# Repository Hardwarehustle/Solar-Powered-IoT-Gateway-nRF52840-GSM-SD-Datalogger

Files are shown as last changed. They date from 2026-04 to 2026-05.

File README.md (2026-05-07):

# Solar-Powered IoT Gateway — nRF52840 + GSM + SD Datalogger
---

## Project Overview

This is a **solar-powered, battery-backed IoT Gateway PCB** built around the **Nordic nRF52840** SoC (Bluetooth 5 + USB + 64 MHz Cortex-M4F). It integrates a complete off-grid power system with MPPT solar charging, 2× AA battery holders, GSM connectivity via SIM800L, timestamped microSD data logging via DS3231 RTC, EEPROM configuration storage, and a u.FL antenna connector — all on a compact square board with 4 mounting holes.

The board is designed for **remote outdoor IoT deployments** such as environmental monitoring, asset tracking, agricultural sensors, and smart metering — where grid power is unavailable and cellular connectivity is the only uplink.

**Key capabilities:**
-  **Solar MPPT charging** of LiPo/Li-ion battery via CN3791
-  **BLE 5.0 / NFC / USB** via nRF52840
-  **GSM 2G connectivity** via SIM800L (SMS, GPRS)
-  **MicroSD card** data logging (SPI, level-shifted via 74LVC125A)
-  **DS3231 RTC** with AT24C32 EEPROM for timestamped logging
-  **SWD JTAG** debug/programming header
-  **FACTORY + RESET** tactile buttons
-  **Power + Status LEDs**

---

##  Project Visuals

### Schematic
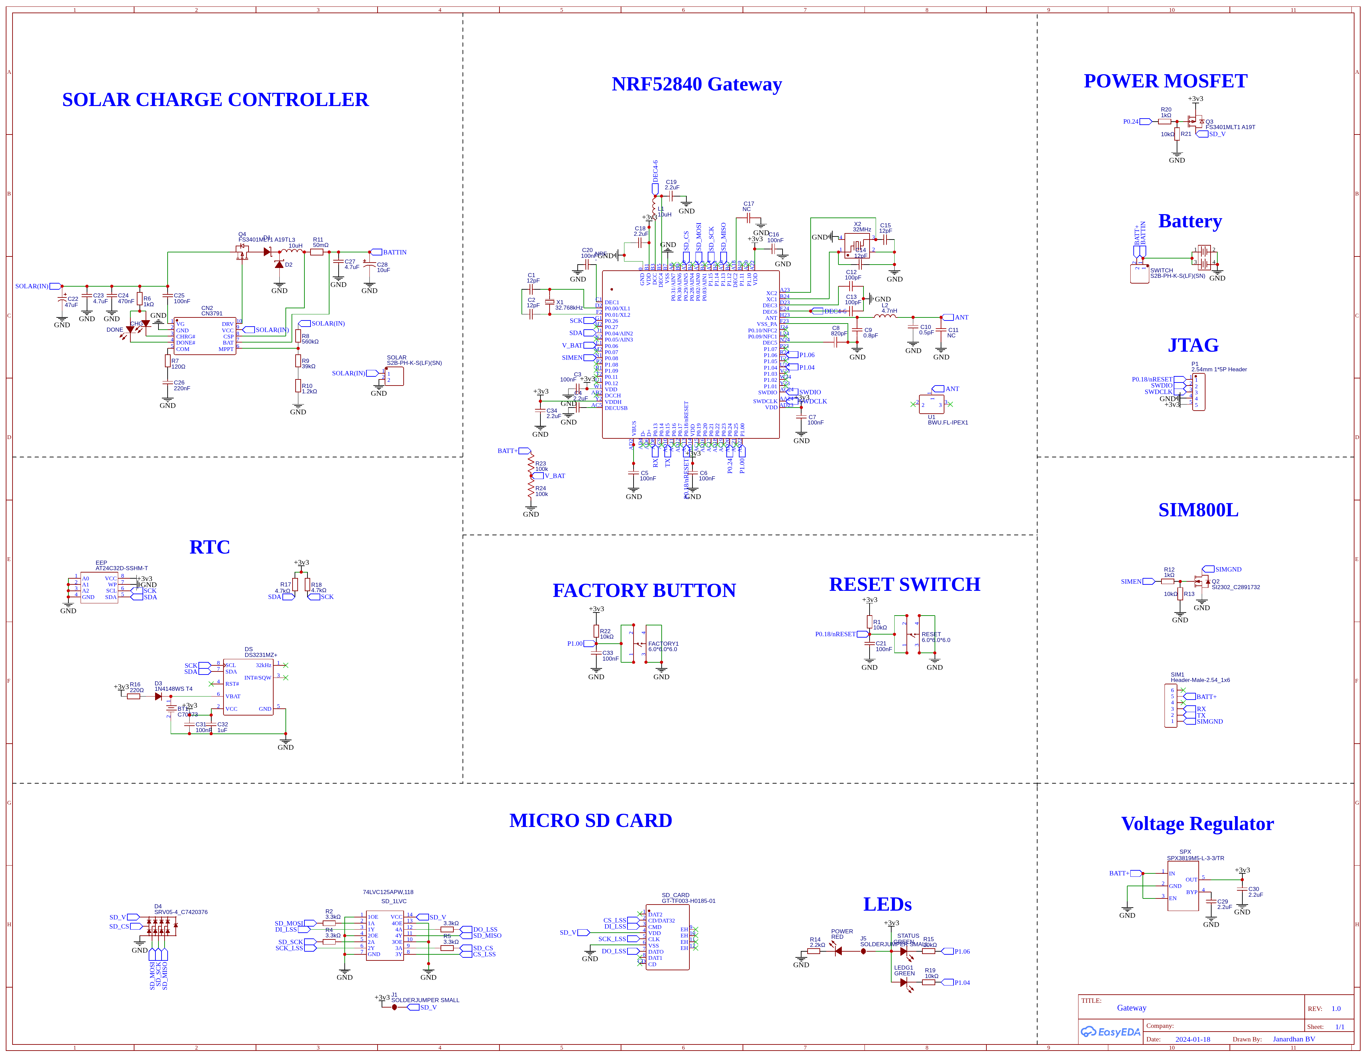
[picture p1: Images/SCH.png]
Schematic


### PCB Layout
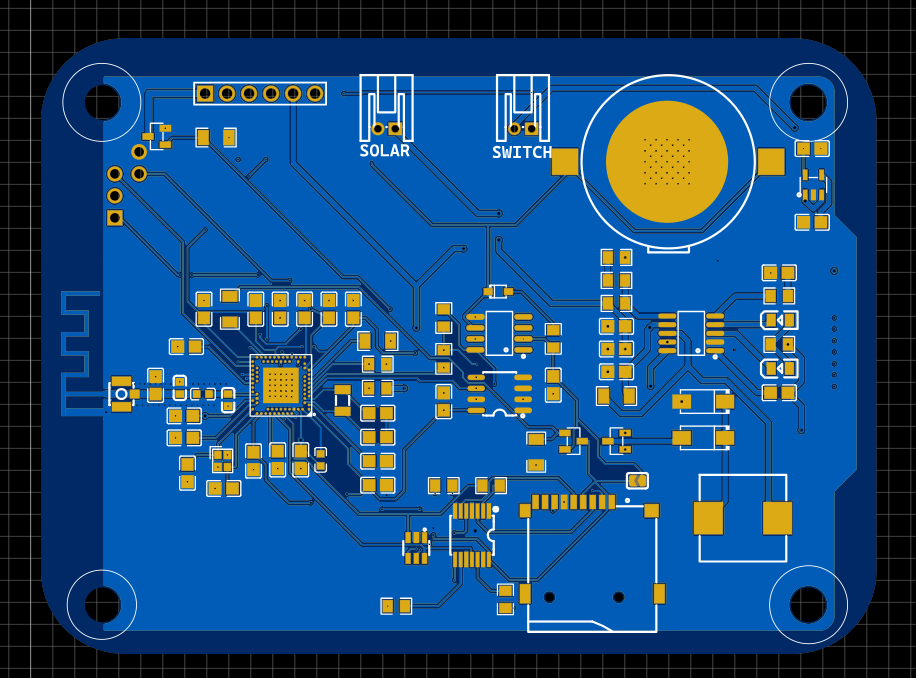
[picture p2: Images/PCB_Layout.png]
PCB Layout


### 3D Board Top View
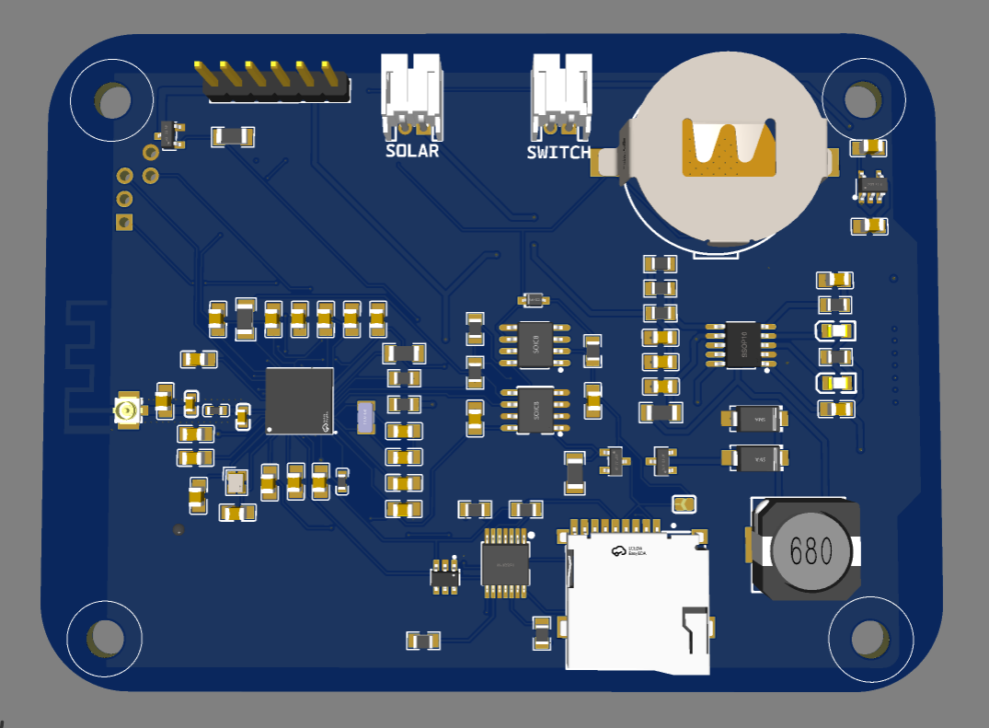
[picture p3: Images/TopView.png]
3D Top View


### 3D Board Bottom View
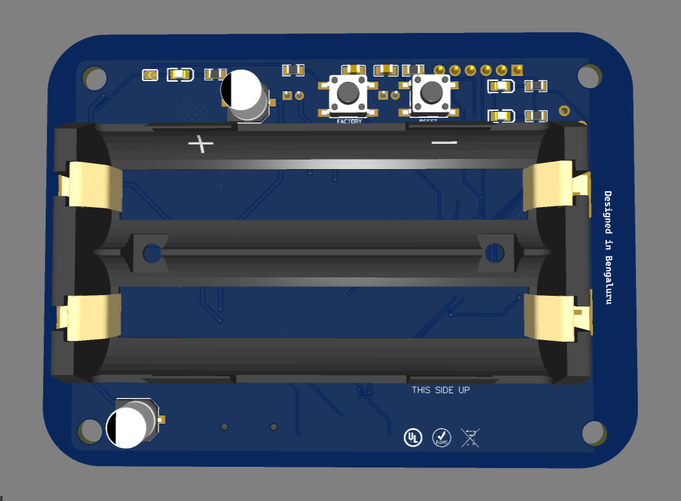
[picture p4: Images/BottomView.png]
3D Bottom View


---

## System Architecture

```
Solar Panel Input (S2B-PH Connector)
      │
      ▼
CN3791 MPPT Solar Charge Controller
      │ (charges at up to 2A, 300 kHz PWM)
      ▼
2× AA Battery Holder (BT1 — bottom side)
      │  BATT+ rail
      ├──► SPX3819M5-L-3.3 LDO ──► +3v3 rail
      │
      └──► SIM800L (BATT+ directly, ~4V peak 2A)
                 │
          SIM Module Header (SIM1, 1×6 pin 2.54mm)

+3v3 rail powers:
  ├── nRF52840 (U_NRF) via VDD
  ├── DS3231MZ+ RTC
  ├── AT24C32D EEPROM
  ├── 74LVC125A (SD level shifter)
  └── SD Card (switched via FS3401 P-MOSFET)

nRF52840 SoC:
  ├── SPI ──► 74LVC125A ──► MicroSD Card
  ├── I2C ──► DS3231 RTC + AT24C32 EEPROM
  ├── UART ──► SIM800L GSM module
  ├── USB D+/D– (native USB full-speed)
  ├── SWD ──► JTAG debug header
  └── u.FL Antenna connector
```

---

## Component BOM

### Core ICs

| Ref | Part | Function |
|:---:|:---|:---|
| NRF | nRF52840 (aQFN-94) | BLE 5.0 + USB + Cortex-M4F SoC @ 64 MHz |
| CN2 | CN3791 | MPPT solar charge controller (up to 2A) |
| SPX | SPX3819M5-L-3.3 | 500mA LDO regulator — Battery → 3.3V |
| SD_1LVC | 74LVC125APW | Quad buffer — SD card SPI level shifting |
| DS | DS3231MZ+ | Ultra-precise ±2ppm I2C RTC with temperature |
| EEP | AT24C32D-SSHM-T | 32Kbit I2C EEPROM for config/calibration |
| SIM800L | SIM800L (via SIM1 header) | Quad-band 2G GSM/GPRS module |

### Power & Switching

| Ref | Part | Function |
|:---:|:---|:---|
| Q2 | SI2302 (C2891732) | N-MOSFET — SIM800L power enable (SIMEN) |
| Q3, Q4 | FS3401MLT1 A19T | P-MOSFET — SD card power switching (SD_V) |
| D3 | 1N4148WS | Schottky diode — RTC VBAT protection |
| D4 | SRV05-4 | TVS array — SD card ESD protection |
| BT1 | C70373 | 2× AA battery holder (bottom-mounted) |

### Connectors

| Ref | Part | Signals |
|:---:|:---|:---|
| SOLAR | S2B-PH-K-S (2-pin JST) | Solar panel input |
| SWITCH | S2B-PH-K-S (2-pin JST) | External power switch |
| SIM1 | HDR 1×6 2.54mm | SIM800L GSM module header |
| P1 | HDR 1×5 2.54mm | UART/GPIO expansion header |
| U1 | BWU.FL-IPEX1 | u.FL antenna connector (nRF52840 ANT) |
| JTAG | SWD header | SWD debug (SWDIO, SWDCLK, GND) |

### Crystals

| Ref | Frequency | Function |
|:---:|:---:|:---|
| X1 | 32.768 kHz | nRF52840 low-frequency crystal (RTC tick) |
| X2 | 32 MHz | nRF52840 high-frequency crystal (RF) |

---

##  Power Architecture

```
Solar Panel (5V–18V) ──► CN3791 MPPT ──► LiPo / 2×AA Battery (BATT+)
                                              │
                        ┌─────────────────────┼─────────────────────┐
                        ▼                     ▼                     ▼
              SPX3819M5 LDO           SI2302 MOSFET (Q2)     Direct BATT+
              (3.3V, 500mA)           SIM800L EN switching    (SIM800L VCC)
                    │
                 +3v3 rail
                    │
     ┌──────────────┼──────────────────────────────┐
     ▼              ▼              ▼               ▼
 nRF52840        DS3231         AT24C32        74LVC125 + SD
```

| Rail | Voltage | Source | Consumers |
|:---:|:---:|:---|:---|
| BATT+ | 3.5–4.2V | CN3791 / Battery | SIM800L, SPX LDO input |
| +3v3 | 3.3V | SPX3819M5 LDO | nRF52840, RTC, EEPROM, SD |
| SD_V | 3.3V | FS3401 P-MOSFET (switchable) | MicroSD card only |

---

## Solar Charge Controller — CN3791

The **CN3791** is a standalone MPPT Li-ion/LiPo battery charger for photovoltaic input. [web:97] Key features:
- **Input:** 5V–18V solar panel via SOLAR JST connector
- **MPPT tracking:** Uses MPPT pin with R8/R9 voltage divider (560kΩ/39kΩ) to set MPPT threshold
- **Max charge current:** Up to 2A (set by R11 = 50mΩ sense resistor: I = 0.1/R11)
- **PWM frequency:** 300 kHz with 10µH inductor (L1)
- **Status outputs:** CHRG# → CHG LED (charging), DONE# → DONE LED (full)
- **Automatic recharge** when battery drops below threshold [web:99]

---

## nRF52840 — Main SoC

| Feature | Detail |
|:---|:---|
| Core | ARM Cortex-M4F @ 64 MHz |
| Flash / RAM | 1 MB / 256 KB |
| BLE | Bluetooth 5.0, 2 Mbps, long range |
| USB | Full-speed USB 2.0 (native, no bridge needed) |
| NFC | NFC-A tag emulation (P0.09/P0.10) |
| GPIO | 48 configurable pins |
| ADC | 8-channel SAR ADC (AIN0–AIN7) |
| Crystals | 32 MHz (RF) + 32.768 kHz (RTC) |
| SWD | JTAG/SWD programming and debug |

---

## DS3231MZ+ RTC + AT24C32 EEPROM

The **DS3231MZ+** provides ±2ppm accuracy timekeeping over I2C (SDA/SCL), with a built-in temperature sensor and battery backup via D3 (1N4148WS) for operation during power loss. [web:101] The **AT24C32D** EEPROM (32Kbit, I2C) shares the same I2C bus for storing gateway configuration, calibration data, and device identity persistently.

---

## MicroSD Card — Level-Shifted SPI

The SD card operates at 3.3V and communicates via SPI (SD_MOSI, SD_MISO, SD_SCK, SD_CS). The **74LVC125A quad bus buffer** handles level shifting between the nRF52840 (3.3V logic) and the SD card. [file:93] An **SRV05-4 TVS diode array (D4)** protects all 4 SPI lines against ESD transients. The SD card power rail (`SD_V`) is switched by two parallel **FS3401 P-MOSFETs (Q3, Q4)** for power gating — the SD card can be completely powered off during sleep for ultra-low power operation.

---

## SIM800L GSM Module

The **SIM800L** connects via UART (TX/RX) to the nRF52840 on SIM1 header. [file:93] It is powered directly from BATT+ through a **SI2302 N-MOSFET (Q2)** controlled by `SIMEN` GPIO, allowing the MCU to power-gate the GSM module for battery saving. Capabilities include:
- Quad-band 2G GSM/GPRS (850/900/1800/1900 MHz)
- SMS sending/receiving for remote alerts
- GPRS data for cloud telemetry upload
- Peak current ~2A — bulk cap C22 (47µF) on BATT+ handles transients

---

## User Interface

| Component | Location | Function |
|:---:|:---:|:---|
| RESET button | Top side (6×6×6 mm) | nRF52840 hardware reset (P0.18/nRESET) |
| FACTORY button | Top side (6×6×6 mm) | Factory reset trigger (P1.00) |
| LEDG1 (Green) | Top side | Power / status LED |
| RED LED | Top side | Charging status (CN3791 CHG output) |
| J1, J5 | Solder jumpers | Configuration options (SD power, UART routing) |

---

## Bring-Up & Testing

### Step 1 — Power Rail Check
- Connect solar panel or apply 4V to BATT+ directly
- Measure SPX3819M5 output: **+3.3V** on VDD of nRF52840
- Verify green LED illuminates (power OK)

### Step 2 — SWD Programming
- Connect J-Link / DAPLink to SWD header (SWDIO, SWDCLK, GND)
- Flash nRF52840 firmware via nRF Connect for Desktop or OpenOCD
- Verify serial output on UART at 115200 baud

### Step 3 — Solar Charging Test
- Connect solar panel to SOLAR JST connector
- Verify CN3791 CHG# LED (RED) lights during charging
- Verify DONE# LED goes off when battery full

### Step 4 — SD Card Test
- Insert microSD (FAT32 formatted)
- Enable SD_V via Q3/Q4 gate GPIO
- Write test file via SPI — verify file on PC

### Step 5 — RTC & EEPROM Test
- Set DS3231 time via I2C
- Power cycle — verify time retained (D3 VBAT path)
- Write/read AT24C32 EEPROM over I2C

### Step 6 — GSM Test
- Enable SIM800L via `SIMEN` GPIO HIGH
- Send AT command via UART → expect `OK`
- Send test SMS — verify delivery

---

## Firmware Stack

```
nRF5 SDK / Zephyr RTOS (nRF52840 target)
├── BLE Stack (SoftDevice S140 or Zephyr BT)
├── UART driver     → SIM800L AT commands
├── SPI driver      → MicroSD (FatFS)
├── I2C driver      → DS3231 RTC + AT24C32 EEPROM
├── GPIO            → SIMEN (SIM power), SD_V (SD power), LEDs
├── ADC             → Battery voltage monitoring (AIN)
└── Power Management → System OFF sleep, GPIO wakeup
```

---

## Design Notes & Cautions

- **nRF52840 RF decoupling** — DEC1–DEC6 capacitor network must be placed within 0.5mm of IC pads per Nordic layout guidelines
- **32 MHz crystal (X2)** load caps (12pF C1/C2) must be placed as close as possible to XC1/XC2 pads
- **CN3791 MPPT resistor divider (R8=560kΩ, R9=39kΩ)** sets the MPPT voltage threshold — verify panel Vmp before changing
- **SIM800L 2A peak current** — C22 (47µF) must be placed close to SIM1 VCC pin; use low-ESR capacitor
- **SD card ESD (D4 = SRV05-4)** — ensure TVS array is between connector and 74LVC125 to protect all 4 SPI lines
- **Solder jumpers J1/J5** — must be configured before first power-on; check schematic notes for correct position
- Board silkscreen reads **"Designed in Bengaluru"** and **"THIS SIDE UP"** — bottom side has battery holder

---

## License

This project is open for educational and personal use.  
© 2024 Janardhan BV — All rights reserved.

---

## Author

**Janardhan BV**  
Embedded Hardware Engineer | PCB Design | Power Electronics  
Bengaluru, India

---
*Solar IoT Gateway — nRF52840 + CN3791 MPPT + SIM800L + DS3231 + MicroSD*

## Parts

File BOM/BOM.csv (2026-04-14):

ID | Name | Designator | Footprint | Quantity | Manufacturer Part | Manufacturer | Supplier | Supplier Part | Price | Pins | 3DModel | Contributor | JLCPCB Part Class | link
1 | 6.0*6.0*6.0 | FACTORY1,RESET | SW-SMD_4P-L6.0-W6.0-P4.50-LS8.6 | 2 | 6.0*6.0*6.0 | BOOMELE(博穆精密) | LCSC | C5127964 | 0.022 | 4 | SW-SMD_4P-L6.0-W6.0-P4.50-LS8.6 | lcsc | Extended Part | https://item.szlcsc.com/2796384.html
2 | BH-18650-B1BA007 | BT2 | 18650 SMD 2P | 1 | BH-18650-B1BA007 | MYOUNG(美阳) | LCSC | C6937126 | 1.748 | 4 | BAT-SMD_BH-18650-B1BA007 | lcsc | Extended Part
3 | 100nF | C21,C33,C3,C5,C6,C7,C16,C20,C25,C31 | C0805 | 10 | 0805B104K500NT | FH(风华) | LCSC | C38141 | 0.005 | 2 | C0805_L2.0-W1.3-H1.3 | lcsc | Extended Part | https://item.szlcsc.com/373011.html
4 | GREEN | LEDG1,STATUS,DONE | LED0805-R-RD | 3 | KT-0805翠绿 | KENTO | LCSC | C2297 | 0.016 | 2 | LED0805-RD | lcsc | Basic Part | https://item.szlcsc.com/88042.html
5 | RED | POWER,CHG | LED0805-R-RD | 2 | NCD0805R1 | 国星光电 | LCSC | C84256 | 0.013 | 2 | LED0805-RD | lcsc | Basic Part | https://item.szlcsc.com/88042.html
6 | SOLDERJUMPER SMALL | J5,J1 | SOLDERJUMPERSMALL | 2 |  |  |  |  |  | 2 |  | dpalmer50
7 | 10kΩ | R1,R15,R19,R22 | R0805 | 4 | 0805W8F1002T5E | UNI-ROYAL(厚声) | LCSC | C17414 | 0.003 | 2 | R0805_L2.0-W1.3-H0.6 | lcsc | Basic Part | https://item.szlcsc.com/142685.html
8 | 2.2kΩ | R14 | R0805 | 1 | 0805W8J0222T5E | UNI-ROYAL(厚声) | LCSC | C26017 | 0.002 | 2 | R0805_L2.0-W1.3-H0.6 | lcsc | Extended Part | https://item.szlcsc.com/142685.html
9 | 47uF | C22 | CAP-SMD_BD6.3-L6.6-W6.6-FD-A | 1 | VZT470M1HTR-0606 | lelon(立隆) | LCSC | C688950 | 0.098 | 2 | CAP-SMD_BD6.3-L6.6-W6.6-FD-A | LCSC | Extended Part | https://atta.szlcsc.com/upload/public/pdf/source/20181114/C278512_F6ABFFB833591ACF6A4B64AEC8B9747F.pdf
10 | 10uF | C28 | CAP-SMD_BD6.3-L6.6-W6.6-LS7.2-FD | 1 | RVT2A100M0607 | HONOR(荣誉) | LCSC | C86606 | 0.036 | 2 | CAP-SMD_BD6.3-L6.6-W6.6-LS7.2-FD | lcsc | Extended Part | https://www.chemi-con.co.jp/products/relatedfiles/capacitor/catalog/PXERA-c.PDF
11 | - | NRF | AQFN-73_BP | 1 | NRF52840-QIAA-R7 | NORDIC | LCSC | C190794 | 6.806 | 74 | AQFN-94_L7.0-W7.0-P0.40_NRF5340-QKAA-R | LCSC | Extended Part
12 | 10uH | L3 | IND-SMD_L10.0-W10.0_CLF10060NIT | 1 | MWSA0603S-100MT | Sunlord(顺络) | LCSC | C132141 |  | 2 | IND-SMD_L10.0-W10.0-H4.1 | LCSC | Extended Part | https://item.szlcsc.com/149963.html
13 | C70373 | BT1 | BAT-SMD_CR2032-3V | 1 | CR2032弯脚电池片铜 3V | Q&J | LCSC | C70373 | 0.048 | 3 | BAT-SMD_CR2032-3V | LCSC | Extended Part | https://item.szlcsc.com/71468.html
14 | 12pF | C1,C2,C14,C15 | C0805 | 4 | 0805CG120J500NT | FH(风华) | LCSC | C1792 | 0.005 | 2 | C0805_L2.0-W1.3-H1.3 | lcsc | Extended Part | https://item.szlcsc.com/373011.html
15 | 2.2uF | C4,C18,C19,C29,C30,C34 | C0805 | 6 | CL21B225KAFNNNE | SAMSUNG(三星) | LCSC | C19110 | 0.016 | 2 | C0805_L2.0-W1.3-H1.3 | lcsc | Extended Part | https://item.szlcsc.com/373011.html
16 | 820pF | C8 | C0805 | 1 | CC0805JRNPO9BN821 | YAGEO(国巨) | LCSC | C113834 | 0.009 | 2 | C0805_L2.0-W1.3-H1.3 | LCSC | Extended Part | https://item.szlcsc.com/373011.html
17 | 100pF | C12,C13 | C0805 | 2 | 0805CG101J500NT | FH(风华) | LCSC | C82028 | 0.006 | 2 | C0805_L2.0-W1.3-H1.3 | lcsc | Extended Part | https://item.szlcsc.com/373011.html
18 | 4.7uF | C23,C27 | C0805 | 2 | CL21A475KAQNNNE | SAMSUNG(三星) | LCSC | C1779 | 0.015 | 2 | C0805_L2.0-W1.3-H1.3 | lcsc | Basic Part | https://item.szlcsc.com/373011.html
19 | 470nF | C24 | C0805 | 1 | CL21B474KBFNNNE | SAMSUNG(三星) | LCSC | C13967 | 0.014 | 2 | C0805_L2.0-W1.3-H1.3 | lcsc | Basic Part | https://item.szlcsc.com/373011.html
20 | 220nF | C26 | C0805 | 1 | CL21B224KBFNNNE | SAMSUNG(三星) | LCSC | C5378 | 0.01 | 2 | C0805_L2.0-W1.3-H1.3 | lcsc | Basic Part | https://item.szlcsc.com/373011.html
21 | 1uF | C32 | C0805 | 1 | CL21B105KBFNNNE | SAMSUNG(三星) | LCSC | C28323 | 0.013 | 2 | C0805_L2.0-W1.3-H1.3 | lcsc | Basic Part | https://item.szlcsc.com/373011.html
22 | 0.8pF | C9 | C0603 | 1 | 0603CG0R8B500NT | FH(风华) | LCSC | C507057 | 0.008 | 2 | C0603_L1.6-W0.8-H0.8 | LCSC | Extended Part | https://item.szlcsc.com/362304.html
23 | 0.5pF | C10 | C0603 | 1 | 0603CG0R5C500NT | FH(风华) | LCSC | C1633 | 0.003 | 2 | C0603_L1.6-W0.8-H0.8 | lcsc | Extended Part | https://item.szlcsc.com/362304.html
24 | CN3791 | CN2 | SSOP-10_L4.9-W3.9-P1.00-LS6.0-BL | 1 | CN3791 | CONSONANCE(上海如韵) | LCSC | C154992 | 0.494 | 10 | SSOP-10_L4.9-W3.9-H1.5-LS6.0-P1.00 | LCSC | Extended Part | https://lcsc.com/eda_search?q=C154992&%26type=1&ref=editor
25 | SS54_C22452 | D1,D2 | SMA_L4.4-W2.8-LS5.4-R-RD | 2 | SS54 | MDD | LCSC | C22452 | 0.036 | 2 | SMA_L4.4-W2.8-LS5.4-R-RD | 立创EDA官方封装库 | Basic Part | https://item.szlcsc.com/310096.html
26 | 1N4148WS T4 | D3 | SOD-323_L1.8-W1.3-LS2.5-RD | 1 | 1N4148WS | CJ(江苏长电/长晶) | LCSC | C2128 | 0.009 | 2 | SOD-323_L1.7-W1.3-H1.1-LS2.5 | lcsc | Basic Part | https://lcsc.com/eda_search?q=C2128&%26type=1&ref=editor
27 | SRV05-4_C7420376 | D4 | SOT-23-6_L2.9-W1.6-P0.95-LS2.8-BL-1 | 1 | SRV05-4 | 宏迦橙 | LCSC | C7420376 | 0.089 | 6 | SOT-23-6_L2.9-W1.6-P0.95-LS2.8-BL-1 | lcsc | Extended Part | https://atta.szlcsc.com/upload/public/pdf/source/20191209/C468225_F5C4BE1FF1893F617C569592E38D23FF.pdf
28 | DS3231MZ+ | DS | SOIC-8_L4.9-W3.9-P1.27-LS6.0-BL | 1 | DS3231MZ+TRL | ADI(亚德诺)/MAXIM(美信) | LCSC | C107410 | 3.112 | 8 | SOIC-8_L4.9-W3.9-H1.7-LS6.0-P1.27 | lcsc | Extended Part | https://lcsc.com/eda_search?q=C107410&%26type=1&ref=editor
29 | AT24C32D-SSHM-T | EEP | SOIC-8_L5.0-W4.0-P1.27-LS6.0-BL | 1 | AT24C32D-SSHM-T | MICROCHIP(美国微芯) | LCSC | C60583 | 0.296 | 8 | SOIC-8_L4.9-W3.9-H1.7-LS6.0-P1.27 | lcsc | Extended Part | https://lcsc.com/eda_search?q=C60583&%26type=1&ref=editor
30 | 10uH | L1 | L0603 | 1 | MCL1608S100MT | Sunlord(顺络) | LCSC | C51942 |  | 2 | L0603_L1.6-W0.8-H0.5_BEAD | lcsc | Extended Part | https://item.szlcsc.com/344093.html
31 | 4.7nH | L2 | L0603 | 1 | VHF160808H4N7ST | FH(风华) | LCSC | C1030 | 0.009 | 2 | L0603_L1.6-W0.8-H0.5_BEAD | lcsc | Extended Part | https://item.szlcsc.com/344093.html
32 | SI2302_C2891732 | Q2 | SOT-23-3_L2.9-W1.3-P1.90-LS2.4-BR | 1 | SI2302 | YONGYUTAI(永裕泰) | LCSC | C2891732 | 0.012 | 3 | SOT-23-3P_L2.9-W1.3-H1.0-LS2.4-P0.95 | LCSC | Extended Part | https://www.diodes.com/assets/Package-Files/SOT23.pdf
33 | FS3401MLT1 A19T | Q3,Q4 | SOT-23-3_L2.9-W1.3-P1.90-LS2.4-BR | 2 | FS3401M | FOSAN(富信) | LCSC | C2936839 | 0.022 | 3 | SOT-23-3P_L2.9-W1.3-H1.0-LS2.4-P0.95 | LCSC | Extended Part | https://www.diodes.com/assets/Package-Files/SOT23.pdf
34 | 3.3kΩ | R2,R3,R4,R5 | R0805 | 4 | 0805W8F3301T5E | UNI-ROYAL(厚声) | LCSC | C26010 | 0.002 | 2 | R0805_L2.0-W1.3-H0.6 | lcsc | Basic Part | https://item.szlcsc.com/142685.html
35 | 1kΩ | R6 | R0805 | 1 | 0805W8F1001T5E | UNI-ROYAL(厚声) | LCSC | C17513 | 0.003 | 2 | R0805_L2.0-W1.3-H0.6 | lcsc | Basic Part | https://item.szlcsc.com/142685.html
36 | 120Ω | R7 | R0805 | 1 | 0805W8F1200T5E | UNI-ROYAL(厚声) | LCSC | C17437 | 0.002 | 2 | R0805_L2.0-W1.3-H0.6 | lcsc | Basic Part | https://item.szlcsc.com/142685.html
37 | 560kΩ | R8 | R0805 | 1 | 0805W8F5603T5E | UNI-ROYAL(厚声) | LCSC | C15785 | 0.002 | 2 | R0805_L2.0-W1.3-H0.6 | lcsc | Extended Part | https://item.szlcsc.com/142685.html
38 | 39kΩ | R9 | R0805 | 1 | 0805W8F3902T5E | UNI-ROYAL(厚声) | LCSC | C25826 | 0.003 | 2 | R0805_L2.0-W1.3-H0.6 | lcsc | Extended Part | https://item.szlcsc.com/142685.html
39 | 1.2kΩ | R10 | R0805 | 1 | 0805W8F1201T5E | UNI-ROYAL(厚声) | LCSC | C17379 | 0.002 | 2 | R0805_L2.0-W1.3-H0.6 | lcsc | Basic Part | https://item.szlcsc.com/142685.html
40 | 220Ω | R16 | R0805 | 1 | 0805W8F2200T5E | UNI-ROYAL(厚声) | LCSC | C17557 | 0.003 | 2 | R0805_L2.0-W1.3-H0.6 | lcsc | Basic Part | https://item.szlcsc.com/142685.html
41 | 4.7kΩ | R17,R18 | R0805 | 2 | 0805W8F4701T5E | UNI-ROYAL(厚声) | LCSC | C17673 | 0.002 | 2 | R0805_L2.0-W1.3-H0.6 | lcsc | Basic Part | https://item.szlcsc.com/142685.html
42 | 50mΩ | R11 | R1206 | 1 | RLM12FTCMR050 | 大毅科技 | LCSC | C912768 | 0.04 | 2 | R1206_L3.2-W1.6-H0.6 | LCSC | Extended Part | https://item.szlcsc.com/311874.html
43 | 1kΩ | R12,R20 | R1206 | 2 | 1206W4F1001T5E | UNI-ROYAL(厚声) | LCSC | C4410 | 0.004 | 2 | R1206_L3.2-W1.6-H0.6 | lcsc | Basic Part | https://item.szlcsc.com/311874.html
44 | 10kΩ | R13,R21 | R1206 | 2 | 1206W4F1002T5E | UNI-ROYAL(厚声) | LCSC | C17902 | 0.005 | 2 | R1206_L3.2-W1.6-H0.6 | lcsc | Basic Part | https://item.szlcsc.com/311874.html
45 | 100k | R23,R24 | R0805 | 2 |  |  |  |  |  | 2 | R0805_L2.0-W1.3-H0.6 | LCEDA_Lib |  | https://item.szlcsc.com/142685.html
46 | 74LVC125APW,118 | SD_1LVC | TSSOP-14_L5.0-W4.4-P0.65-LS6.4-BL | 1 | 74LVC125APW,118 | Nexperia(安世) | LCSC | C6059 | 0.646 | 14 | TSSOP-14_L5.0-W4.4-H1.0-LS6.4-P0.65 | lcsc | Extended Part | https://item.szlcsc.com/8137.html
47 | GT-TF003-H0185-01 | SD_CARD | TF-SMD_GT-TF003-H0185-01 | 1 | GT-TF003-H0185-01 | G-Switch(品赞) | LCSC | C5155563 | 0.192 | 13 | TF-SMD_GT-TF003-H0185-01 | lcsc | Extended Part | https://lcsc.com/eda_search?q=C5155563&%26type=1&ref=editor
48 | S2B-PH-K-S(LF)(SN) | SOLAR,SWITCH | CONN-TH_S2B-PH-K-S-LF-SN | 2 | S2B-PH-K-S(LF)(SN) | JST | LCSC | C173752 | 0.037 | 2 | CONN-TH_HR-PH2.0-WI-2P | LCSC | Extended Part | https://atta.szlcsc.com/upload/public/pdf/source/20180327/C173752_5C91EDA4B54CB1D33BA17C4D2B983D44.pdf
49 | SPX3819M5-L-3-3/TR | SPX | SOT-23-5_L3.0-W1.7-P0.95-LS2.8-BL | 1 | SPX3819M5-L-3-3/TR | MaxLinear | LCSC | C9055 | 0.173 | 5 | SOT-23-5_L2.9-W1.6-H1.1-LS2.8-P0.95 | lcsc | Extended Part | https://item.szlcsc.com/236104.html
50 | BWU.FL-IPEX1 | U1 | IPEX-SMD_BWIPX-1-001E | 1 | BWU.FL-IPEX1 | BAT WIRELESS(蝙蝠无线) | LCSC | C5137195 | 0.04 | 3 | IPEX-SMD_BWIPX-1-001E | lcsc | Extended Part | https://item.szlcsc.com/508501.html
51 | 32.768kHz | X1 | FC-135R_L3.2-W1.5 | 1 | Q13FC13500004 | EPSON(爱普生) | LCSC | C32346 | 0.176 | 2 | SMD-3215_2P_L3.2-W1.5-H0.8 | 官方封装库 | Basic Part | https://item.szlcsc.com/49622.html
52 | 32MHz | X2 | CRYSTAL-SMD_4P-L2.0-W1.6-BL | 1 | XL7EL89CKI-111YLC-32M | YXC(扬兴晶振) | LCSC | C2965582 | 0.071 | 4 | CRYSTAL-SMD_4P-L2.0-W1.6-BL | lcsc | Extended Part | https://item.szlcsc.com/248817.html

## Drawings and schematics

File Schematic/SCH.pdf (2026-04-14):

# SOLAR CHARGE CONTROLLER

# Battery

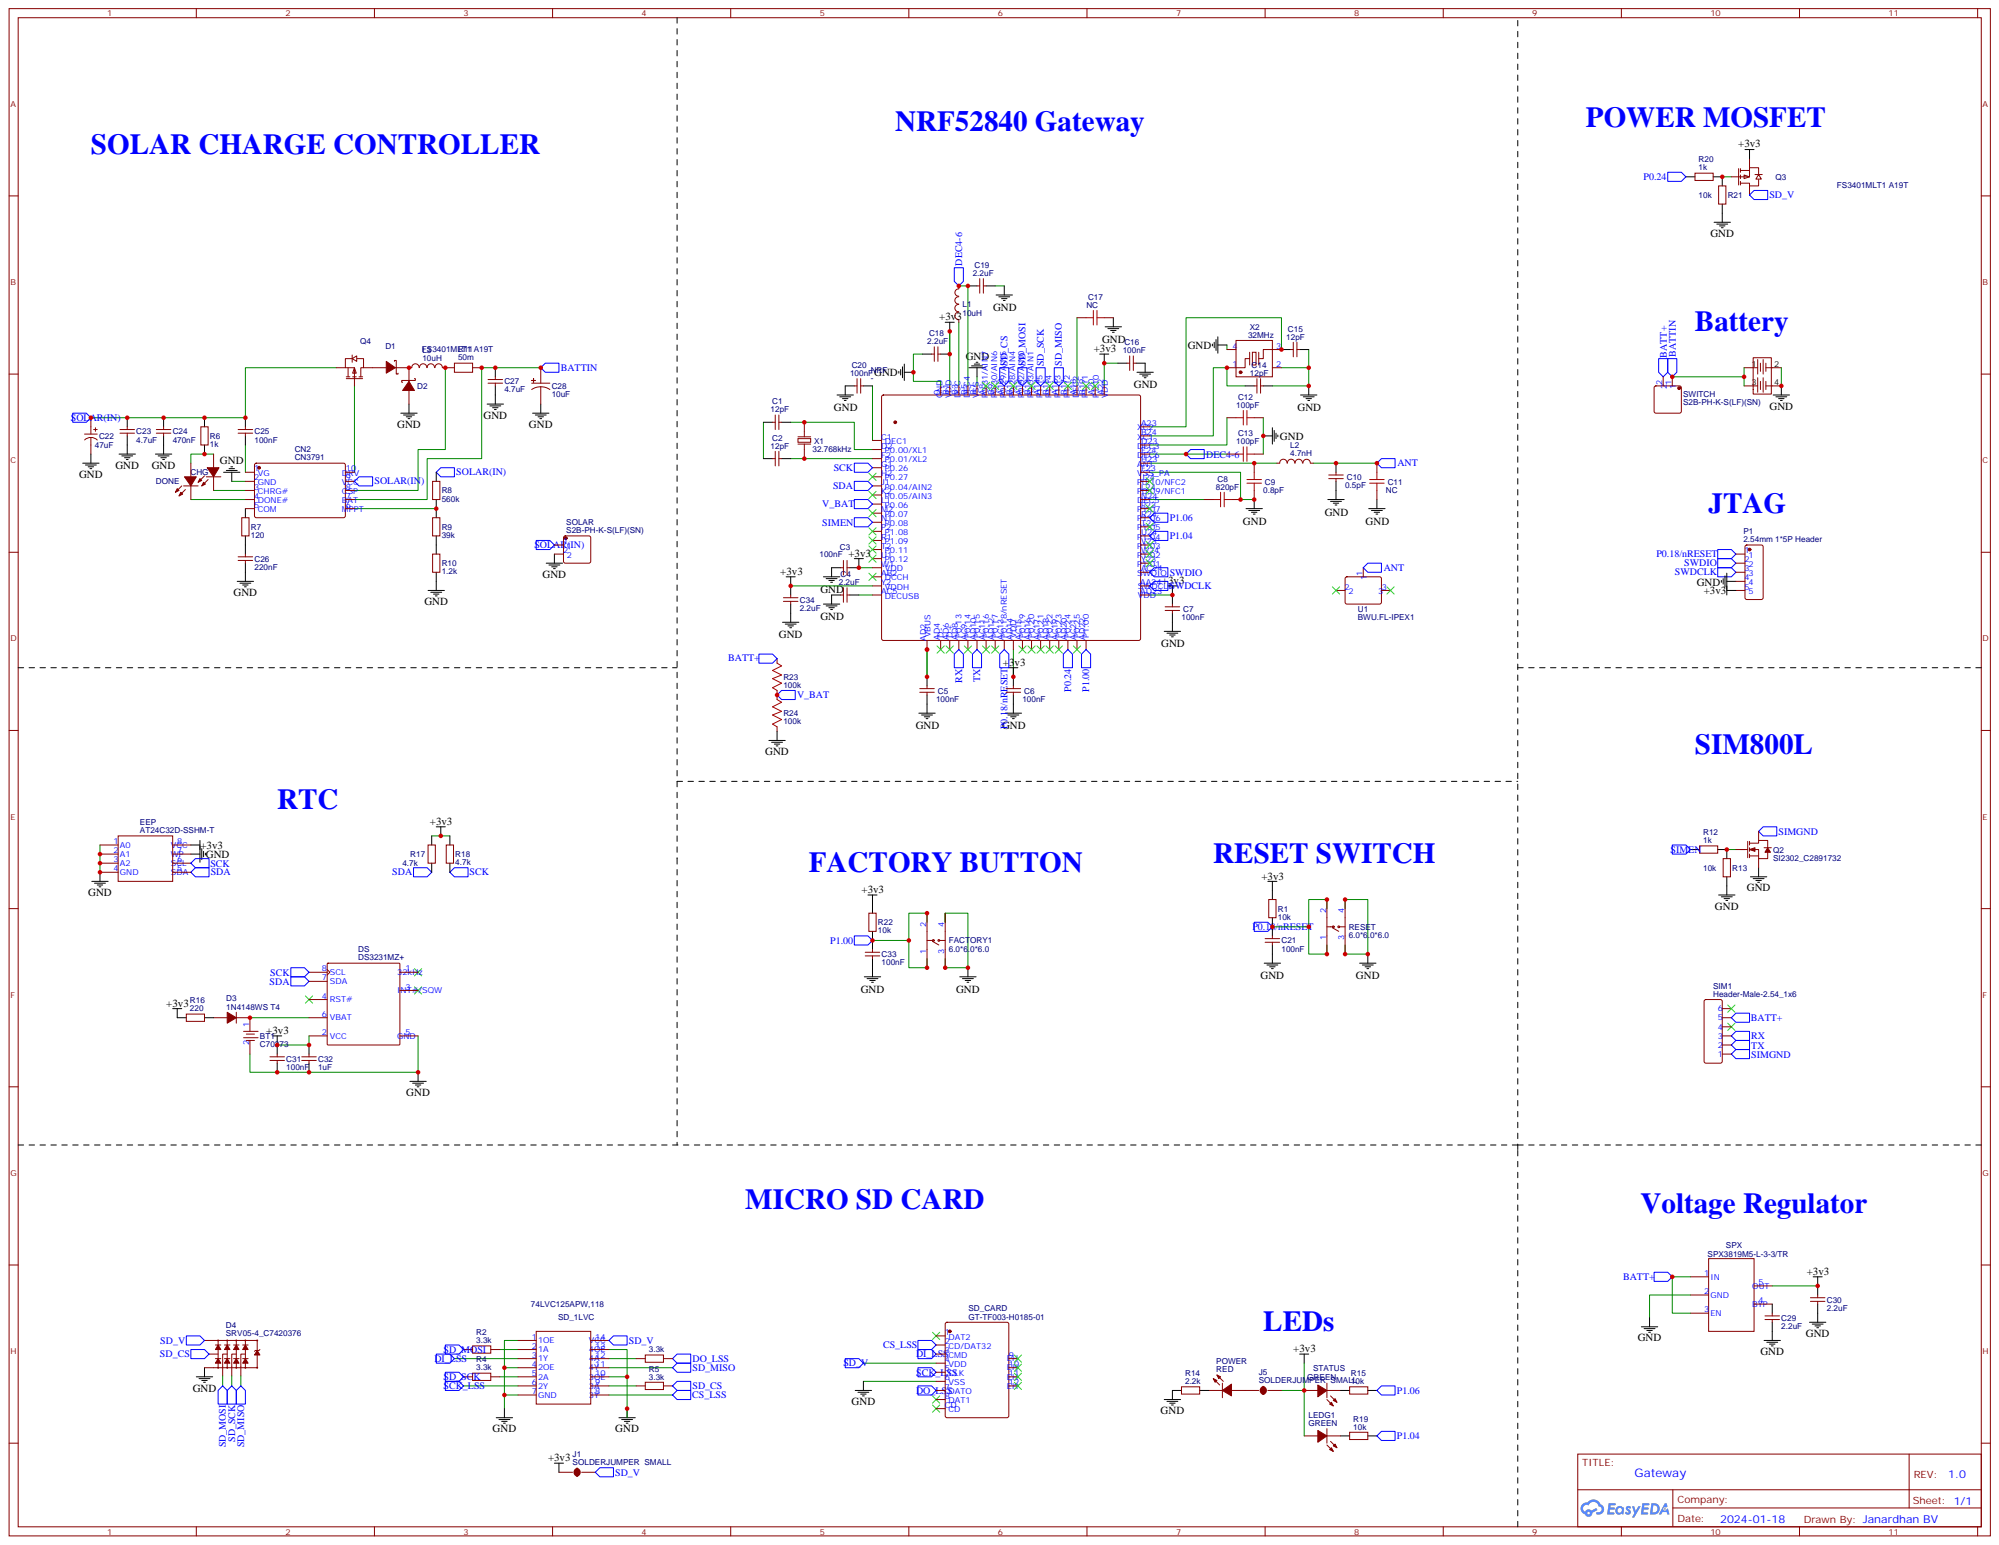
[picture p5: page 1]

Drawn By: Janardhan BV

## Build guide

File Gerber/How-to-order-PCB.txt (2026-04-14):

How to Order PCB

Please refer to:
https://docs.easyeda.com/en/PCB/Order-PCB

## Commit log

2026-04-14 Update visuals section in README
    Added schematic and PCB layout images to README.
2026-05-07 Fix formatting in README for Power Architecture
    Correct formatting of the Power Architecture section.
